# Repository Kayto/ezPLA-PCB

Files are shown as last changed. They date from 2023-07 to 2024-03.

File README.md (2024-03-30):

# ezPLA

C64 PLA replacement based on Altera EPM7032 CPLD chip.

For more information check: https://ezcontents.org/commodore-64-pla-chip-replacement
Tests (includes video): https://ezcontents.org/commodore-64-custom-pla-chip-test

To load the custom symbols and footprints correctly you can edit the files: fp-lib-table and sym-lib-table and change the working directory before loading the project inside KiCad. Or (if you are using Windows) you can also place the project files inside: C:/Projects/KiCAD/ezPLA/

License: CC-BY-SA https://creativecommons.org/licenses/by-sa/4.0/

## Revision Status

Revision 2.0 - July 2023

**This fork by Kayto(@AdamT117) adds the CASRAM delay NAND gate to the PCB.**
[Tested working on a 250407 board.](https://twitter.com/AdamT117/status/1774082185294700785/photo/1)

### Jumper Settings

Solder Jumpers have been added to the back of the PCB to allow some element of control over the CASRAM delay, using up the remaining spare gates on the 74LS00.
Not sure this is really needed but provides greater flexibility (see below). 

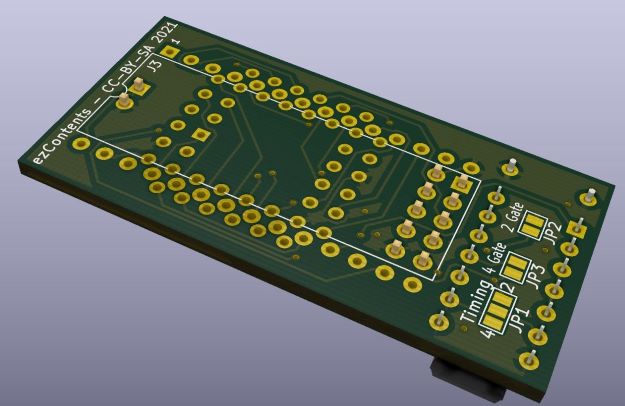
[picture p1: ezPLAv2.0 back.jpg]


The jumpers therefore allow the following;

**2 gate delay**

* JP1 - close label 2 pad to centre pad
* JP2 - close
* JP3 - open

**4 gate delay**
* JP1 - close label 4 pad to centre pad
* JP2 - open
* JP3 - close

### CASRAM delay
The [ezContents](https://ezcontents.org/troubleshooting-c64-pla-chip-replacement) blog provides a fantastic write up on the CASRAM delay.

The propagation delays of original PLAs are of the order of 25 ns ± 5 ns.

The CASRAM delay is introduced in the ezPLA by the switching delay within the added NAND gates - as the gates are inverting then the signal needs to be run through a pair of gates to remove the inversion.
According to the blog entry a 10ns delay was introduced using a pair of NAND gates of a 74LS00. This was versus a 3 to 15ns gate delay quoted in the data sheet - so looks to be around 5 ns per gate.

It is therefore anticipated that delays between 6 ns and 30 ns can be achieved with a 2 input quad NAND gate. The use of the extra gates introduced by the 4 gate jumpers is likely to reach a 20 ns delay.
Alternative NAND gates are also an option to control the delay, albeit a bit trial and error. For example the SN7438 quotes typical gate delays of 11 ns to 14 ns.

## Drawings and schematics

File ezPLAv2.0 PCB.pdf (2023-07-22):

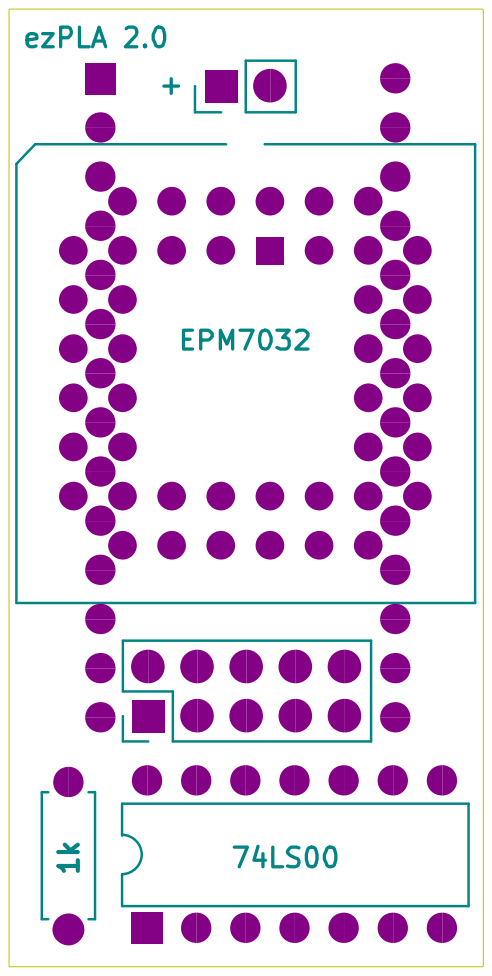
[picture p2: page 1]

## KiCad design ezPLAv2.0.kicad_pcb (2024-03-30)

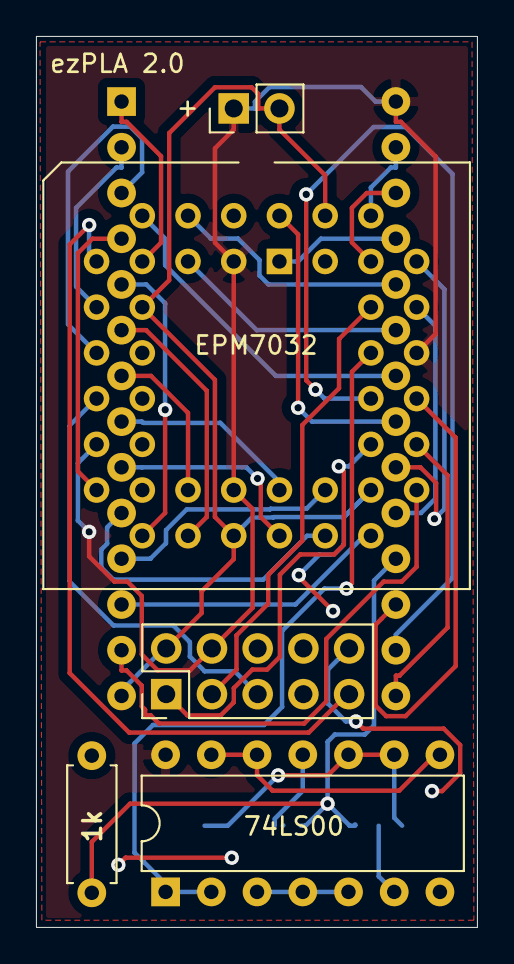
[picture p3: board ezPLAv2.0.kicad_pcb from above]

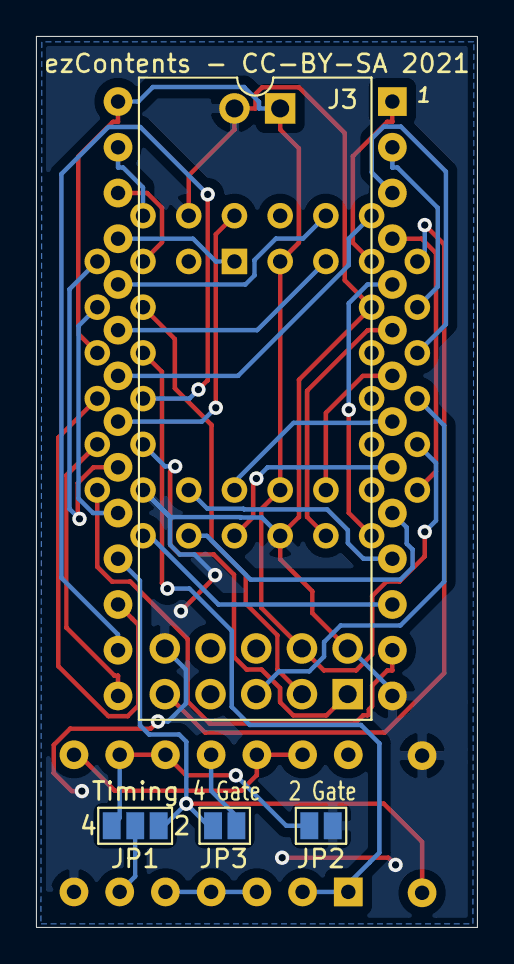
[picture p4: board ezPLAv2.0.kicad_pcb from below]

Board: 2 copper layers, 24.5 x 49.5 mm, 9 parts (4 on the bottom side), 38 nets.

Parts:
J1: JTAG-10; PinHeader_2x05_P2.54mm_Vertical
J2: Power; PinHeader_1x02_P2.54mm_Vertical
J3: PLA-headers; DIP-28_W15.24mm_mirrored
JP1: Jumper_3_Open; SolderJumper-3_P1.3mm_Open_Pad1.0x1.5mm_NumberLabels
JP2, JP3: Jumper_2_Open; SolderJumper-2_P1.3mm_Open_Pad1.0x1.5mm
R1: 1k; R_Axial_DIN0207_L6.3mm_D2.5mm_P7.62mm_Horizontal
U1: 74LS00; DIP-14_W7.62mm
U2: EPM7032; PLCC-44_THT-Socket

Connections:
A12: J3.27, U2.40
A13: J3.2, U2.9
A14: J3.3, U2.11
A15: J3.4, U2.17
AEC: J3.25, U2.1
BA: J3.26, U2.41
BASIC: J3.17, U2.33
CAS: J3.9, U2.24
CASRAM: U1.1, U1.2, U2.36
CASRAM(d): J3.18, JP1.3, JP3.1, R1.1
CHAREN: J3.6, U2.20
CHAROM: J3.15, U2.31
EXROM: J3.23, U2.5
GAME: J3.22, U2.6
GND: J1.2, J1.10, J2.2, J3.14, JP2.2, R1.2, U1.7, U2.10, U2.22, U2.30, U2.42
GRW: J3.13, U2.29
HIRAM: J3.7, U2.21
IO: J3.12, U2.28
KERNAL: J3.16, U2.34
LORAM: J3.8, U2.25
NC1: J3.1, U2.8
unnamed: JP1.1, JP2.1, U1.9, U1.10
unnamed: JP1.2, U1.6
unnamed: JP3.2, U1.11
unnamed: U1.3, U1.4, U1.5
unnamed: U1.8, U1.12, U1.13
OE: J3.19, U2.37
ROMH: J3.10, U2.26
ROML: J3.11, U2.27
RW: J3.24, U2.4
TCK: J1.1, U2.32
TDI: J1.9, U2.7
TDO: J1.3, U2.38
TMS: J1.5, U2.13
VA12: J3.20, U2.39
VA13: J3.21, U2.44
VA14: J3.5, U2.18
VCC: J1.4, J2.1, J3.28, U1.14, U2.3, U2.15, U2.23, U2.35

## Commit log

2023-07-11 rev2.0 PCB with NAND Gate CASRAM delay
    [ezPLA-B_Cu.gbl, ezPLA-B_Mask.gbs, ezPLA-B_Paste.gbp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]
2023-07-22 jumpers added
    [ezPLA.drl, ezPLAv2.0-B_Cu.gbl, ezPLAv2.0-B_Mask.gbs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]
2023-07-24 Test PCB added
    [ezPLAv2.0-B_Cu.gbl, ezPLAv2.0-B_Mask.gbs, ezPLAv2.0-B_Paste.gbp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]
2024-03-30 Update README.md
    removed test board
2024-03-30 Test board removed
    [ezPLAv2.0-B_Cu.gbl, ezPLAv2.0-B_Mask.gbs, ezPLAv2.0-B_Paste.gbp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]

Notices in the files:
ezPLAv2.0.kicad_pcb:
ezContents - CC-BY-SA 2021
